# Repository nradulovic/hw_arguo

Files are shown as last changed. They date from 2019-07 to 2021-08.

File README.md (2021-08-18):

Compact amplifier
=================

This amplifier is intended to be used as a small desktop amplifier. It has no
fancy stuff. It does not even have a volume knob.

It has a short-circuit protection and all the necessary filtering on the inputs
and outputs.

The input is single-ended. 

It has two types of boards:
 - Amplifier board: Mono channel.
 - Power supply board with speaker protection & mute and LED indication.

The complete model of the amplifier case layout is based on Dayens Ampino power 
amplifier.

Amplifier board
===============

Description
-----------

The board contains one amplifier with short-circuit proction and input and
output filters.

Dimensions
----------

Max width: 200mm
Max height: 100mm

Connections
-----------

* Power supply connectors: Vcc, GND, Vee.
* Output connectors: Out, GND.
* Input connector: In, SGND.

Power supply board
==================

Description
-----------

Dimensions
----------

Max width: 140mm
Max height: 100mm

Connections
-----------

* AC Voltage input: Live, Neutral, Earth.
* Switch: CN1, CN2.
* Primary output: Live, Neutral, Earth.
* Secondary input: AC1, GND, AC2.
* DC output: Vcc, GND, Vee.
* Amplifier input: OutL, GND, OutR, GND
* Amplifier output: OutL, GND, OutR, GND
* LED indicator (POWER/FAILURE/OVERLOAD): Anode, Cathode.
* Mute key: K1, K2.

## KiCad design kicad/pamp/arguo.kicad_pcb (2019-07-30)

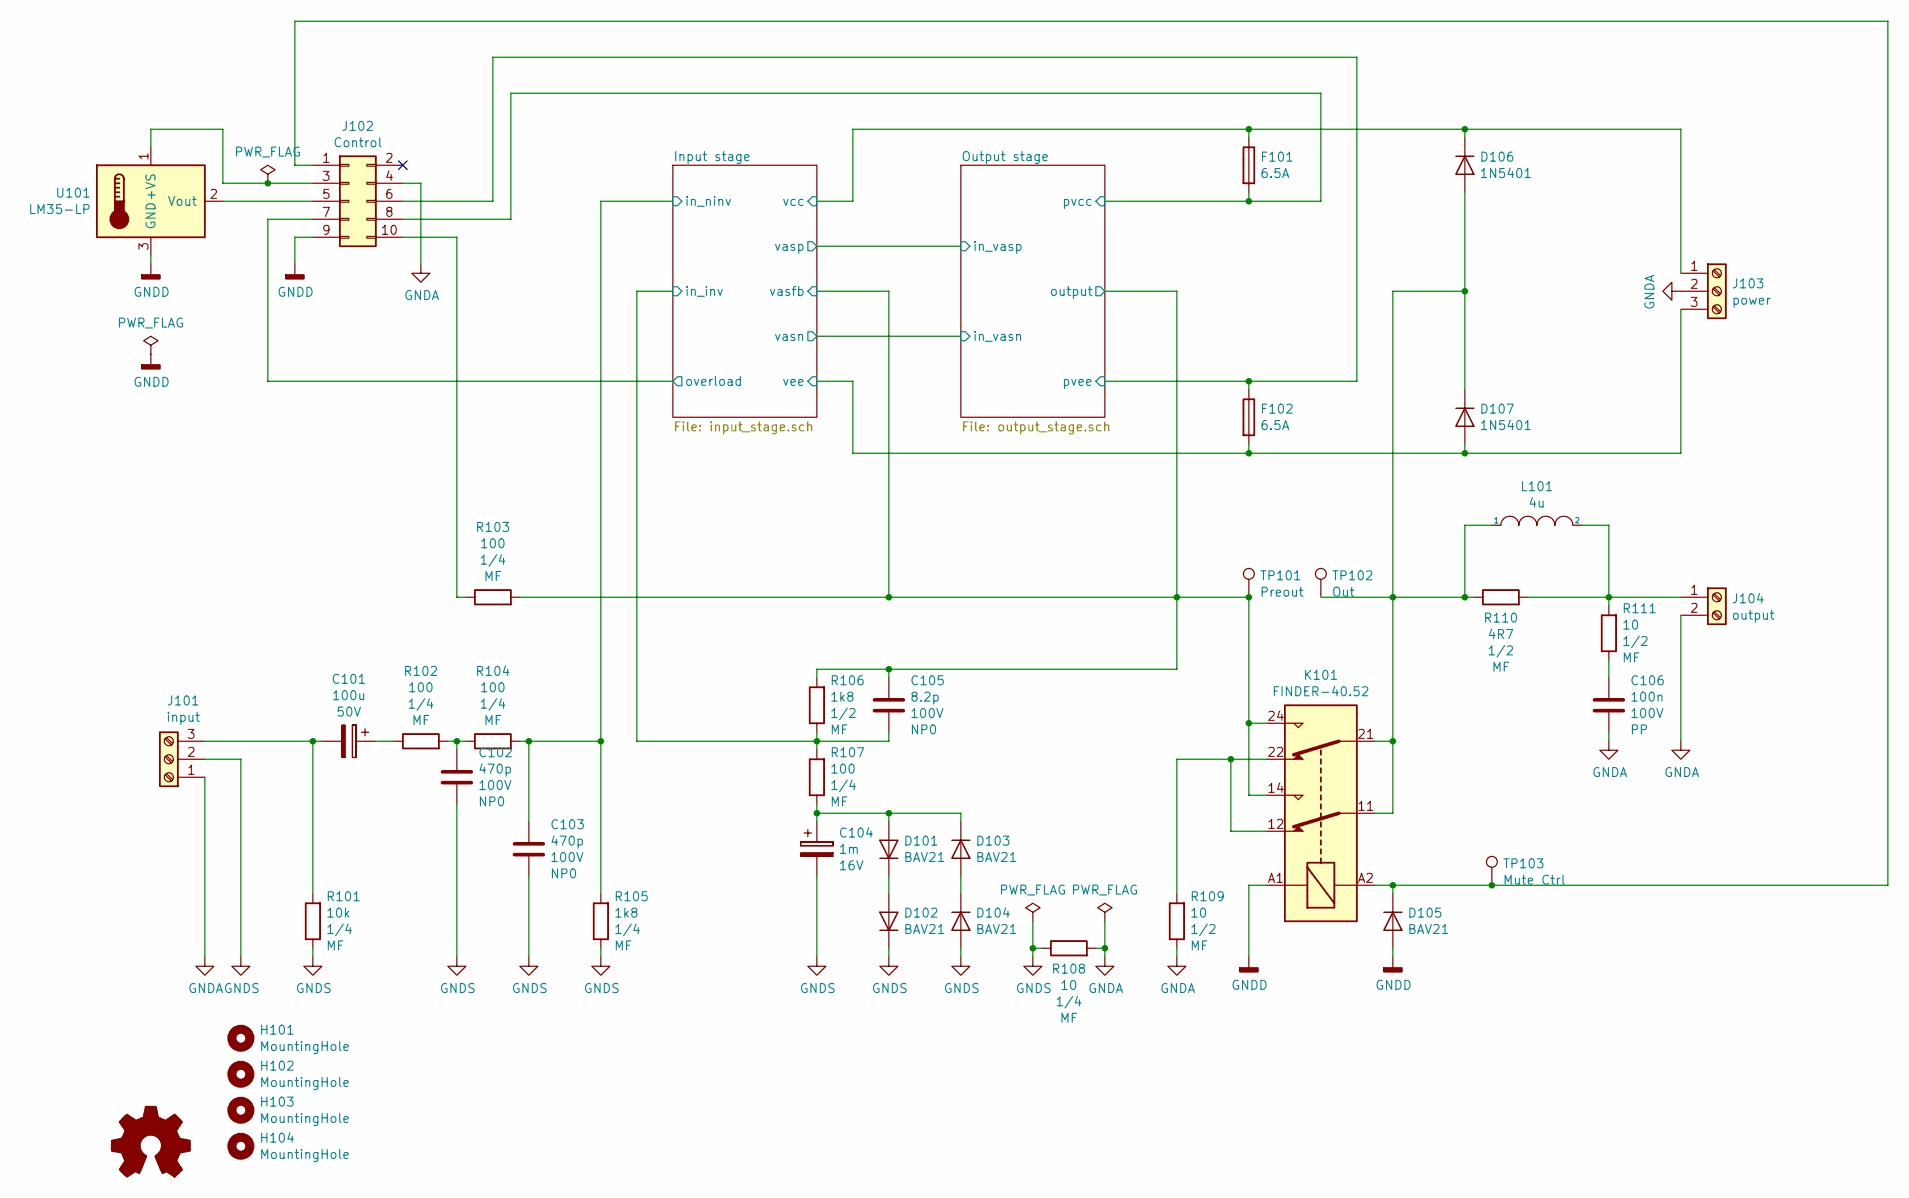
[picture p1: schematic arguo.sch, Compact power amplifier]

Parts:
C101: 100u; CP_Radial_D10.0mm_P3.50mm; Voltage 50V
C102, C103: 470p; C_Disc_D8.0mm_W2.5mm_P5.00mm; Voltage 100V
C104: 1m; CP_Radial_D10.0mm_P3.50mm; Voltage 16V
C105: 8.2p; C_Disc_D3.0mm_W2.0mm_P2.50mm; Voltage 100V
C106: 100n; C_Rect_L7.2mm_W5.5mm_P5.00mm_FKS2_FKP2_MKS2_MKP2; Voltage 100V
D101, D102, D103, D104, D105: BAV21; D_DO-41_SOD81_P7.62mm_Horizontal
D106, D107: 1N5401; D_DO-201AD_P15.24mm_Horizontal
F101, F102: 6.5A; Fuseholder_Cylinder-5x20mm_Schurter_0031_8201_Horizontal_Op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
H101, H102, H103, H104: MountingHole; MountingHole_3.2mm_M3_Pad
J101: input; TerminalBlock_Phoenix_PT-1,5-3-3.5-H_1x03_P3.50mm_Horizontal
J102: Control; IDC-Header_2x05_P2.54mm_Vertical
J103: power; PhoenixContact_MCV_1,5_3-G-3.81_1x03_P3.81mm_Vertical
J104: output; PhoenixContact_MCV_1,5_2-G-3.81_1x02_P3.81mm_Vertical
K101: FINDER-40.52; Relay_DPDT_Finder_40.52
L101: 4u; L_Axial_L29.9mm_D14.0mm_P7.62mm_Vertical_Vishay_IHA-105
R101: 10k; R_Axial_DIN0207_L6.3mm_D2.5mm_P10.16mm_Horizontal
R102, R103, R104, R107: 100; R_Axial_DIN0207_L6.3mm_D2.5mm_P10.16mm_Horizontal
R105: 1k8; R_Axial_DIN0207_L6.3mm_D2.5mm_P10.16mm_Horizontal
R106: 1k8; R_Axial_DIN0411_L9.9mm_D3.6mm_P12.70mm_Horizontal
R108: 10; R_Axial_DIN0207_L6.3mm_D2.5mm_P10.16mm_Horizontal
R109, R111: 10; R_Axial_DIN0411_L9.9mm_D3.6mm_P12.70mm_Horizontal
R110: 4R7; R_Axial_DIN0411_L9.9mm_D3.6mm_P12.70mm_Horizontal
TP101: Preout; TestPoint_Bridge_Pitch2.54mm_Drill0.7mm
TP102: Out; TestPoint_Bridge_Pitch2.54mm_Drill0.7mm
TP103: Mute Ctrl; TestPoint_Bridge_Pitch2.54mm_Drill0.7mm
U101: LM35-LP; TO-92L_Inline_Wide

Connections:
/Input stage/in_inv: C105.2, R106.1, R107.2; also elsewhere on the board
/Input stage/in_ninv: C103.2, R104.2, R105.2; also elsewhere on the board
/Input stage/overload: J102.7; also elsewhere on the board
/Input stage/vcc: D106.1 (K), F101.1, J103.1; also elsewhere on the board
/Input stage/vee: D107.2 (A), F102.2, J103.3; also elsewhere on the board
/Output stage/output: C105.1, K101.14, K101.24, R103.2, R106.2, TP101.1; also elsewhere on the board
/Output stage/pvcc: F101.2, J102.8; also elsewhere on the board
/Output stage/pvee: F102.1, J102.6; also elsewhere on the board
GNDA: C106.2, J101.1, J102.4, J103.2, J104.2, R108.2, R109.1; also elsewhere on the board
GNDD: D105.2 (A), J102.9, K101.A1, U101.3 (GND)
GNDS: C102.1, C103.1, C104.2, D102.1 (K), D104.2 (A), J101.2, R101.1, R105.1, R108.1
unnamed: C101.1, R102.1
unnamed: C101.2, J101.3, R101.2
unnamed: C102.2, R102.2, R104.1
unnamed: C104.1, D101.2 (A), D103.1 (K), R107.1
unnamed: C106.1, R111.1
unnamed: D101.1 (K), D102.2 (A)
unnamed: D103.2 (A), D104.1 (K)
unnamed: D105.1 (K), J102.1, K101.A2, TP103.1
unnamed: D106.2 (A), D107.1 (K), K101.11, K101.21, L101.1, R110.1, TP102.1
unnamed: J102.3, U101.1 (+VS)
unnamed: J102.5, U101.2 (Vout)
unnamed: J102.10, R103.1
unnamed: J104.1, L101.2, R110.2, R111.2
unnamed: K101.12, K101.22, R109.2

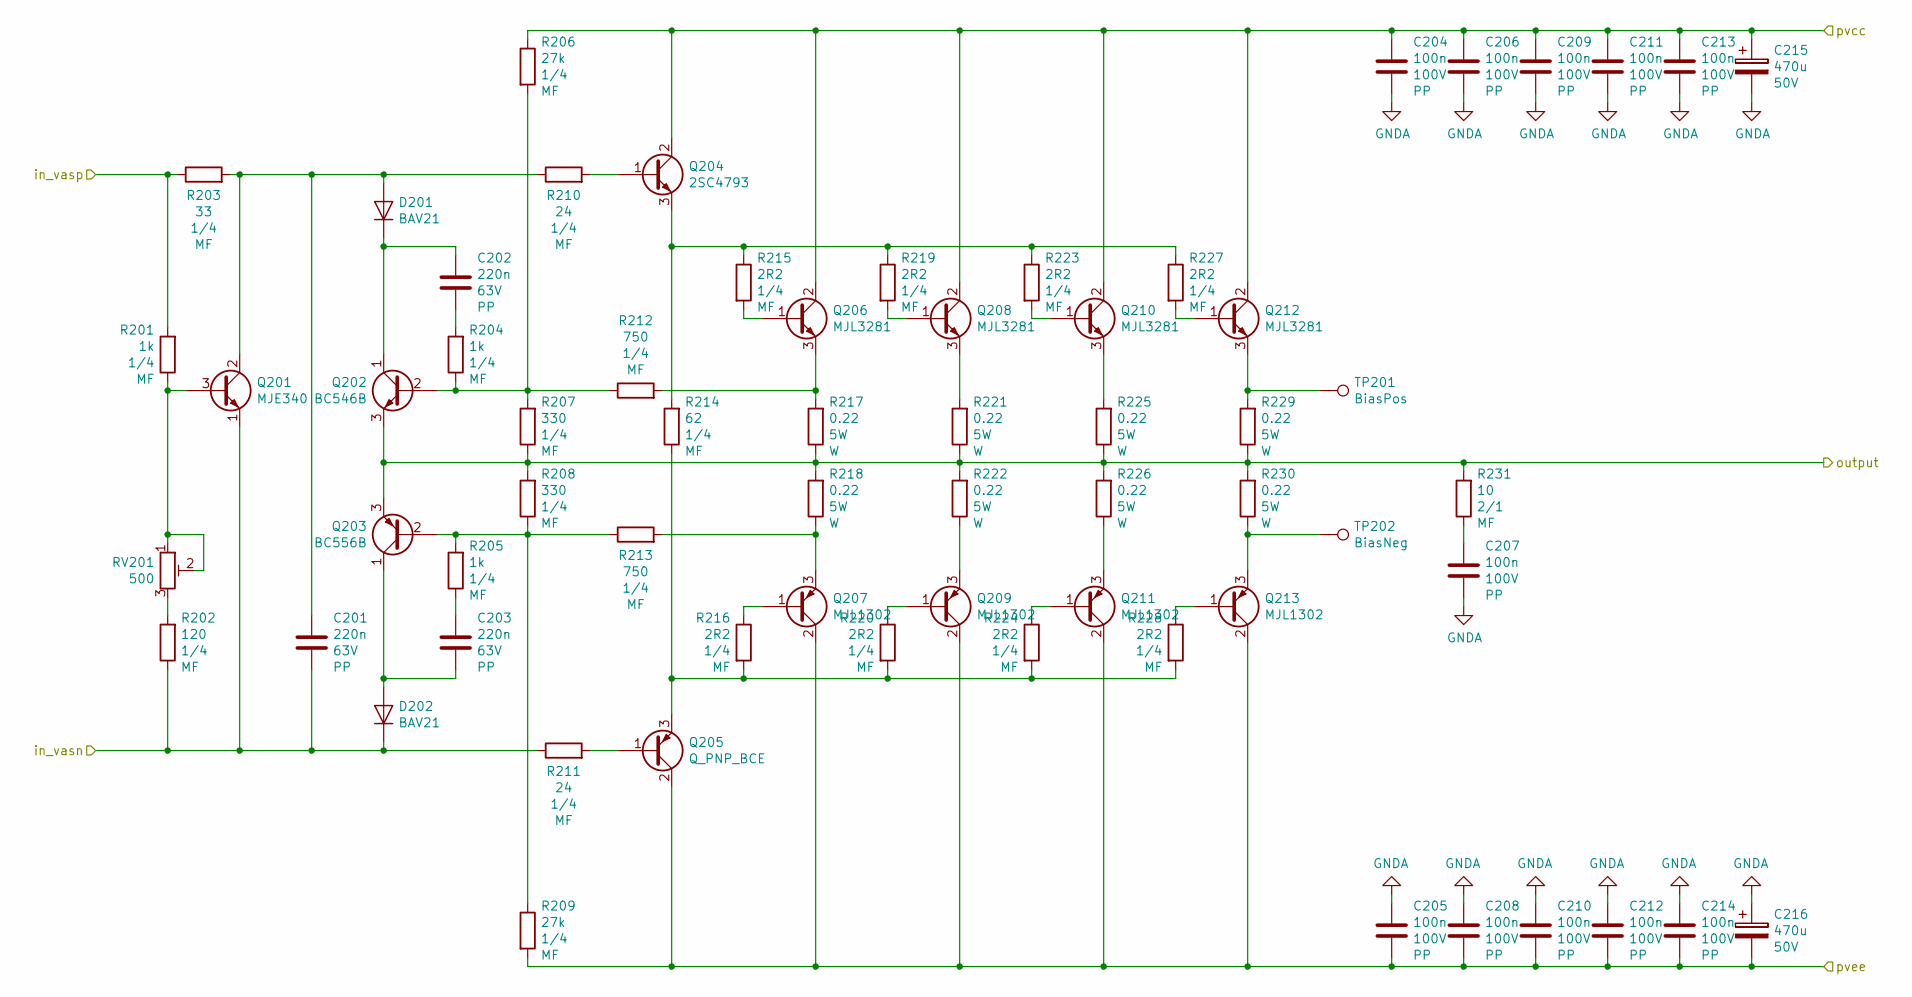
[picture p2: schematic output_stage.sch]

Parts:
C201, C202, C203: 220n; C_Rect_L7.2mm_W4.5mm_P5.00mm_FKS2_FKP2_MKS2_MKP2; Voltage 63V
C204, C205, C206, C207, C208, C209, C210, C211, C212, C213, C214: 100n; C_Rect_L7.2mm_W5.5mm_P5.00mm_FKS2_FKP2_MKS2_MKP2; Voltage 100V
C215, C216: 470u; CP_Radial_D17.0mm_P7.50mm; Voltage 50V
D201, D202: BAV21; D_DO-41_SOD81_P7.62mm_Horizontal
Q201: MJE340; TO-126-3_Vertical
Q202: BC546B; TO-92L_Inline_Wide
Q203: BC556B; TO-92L_Inline_Wide
Q204: 2SC4793; TO-220-3_Vertical
Q205: Q_PNP_BCE; TO-220-3_Vertical
Q206, Q208, Q210, Q212: MJL3281; TO-264-3_Vertical
Q207, Q209, Q211, Q213: MJL1302; TO-264-3_Vertical
R201, R204, R205: 1k; R_Axial_DIN0207_L6.3mm_D2.5mm_P10.16mm_Horizontal
R202: 120; R_Axial_DIN0207_L6.3mm_D2.5mm_P10.16mm_Horizontal
R203: 33; R_Axial_DIN0207_L6.3mm_D2.5mm_P10.16mm_Horizontal
R206, R209: 27k; R_Axial_DIN0207_L6.3mm_D2.5mm_P10.16mm_Horizontal
R207, R208: 330; R_Axial_DIN0207_L6.3mm_D2.5mm_P10.16mm_Horizontal
R210, R211: 24; R_Axial_DIN0207_L6.3mm_D2.5mm_P10.16mm_Horizontal
R212, R213: 750; R_Axial_DIN0207_L6.3mm_D2.5mm_P10.16mm_Horizontal
R214: 62; R_Axial_DIN0207_L6.3mm_D2.5mm_P10.16mm_Horizontal
R215, R216, R219, R220, R223, R224, R227, R228: 2R2; R_Axial_DIN0207_L6.3mm_D2.5mm_P10.16mm_Horizontal
R217, R218, R221, R222, R225, R226, R229, R230: 0.22; R_Axial_Power_L20.0mm_W6.4mm_P25.40mm
R231: 10; R_Axial_DIN0411_L9.9mm_D3.6mm_P12.70mm_Horizontal
RV201: 500; Potentiometer_ACP_CA9-V10_Vertical
TP201: BiasPos; TestPoint_Bridge_Pitch2.54mm_Drill0.7mm
TP202: BiasNeg; TestPoint_Bridge_Pitch2.54mm_Drill0.7mm

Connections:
/Output stage/in_vasn: C201.2, D202.1 (K), Q201.1 (E), R202.1, R211.1; also elsewhere on the board
/Output stage/in_vasp: R201.2, R203.1; also elsewhere on the board
/Output stage/output: Q202.3 (E), Q203.3 (E), R207.1, R208.2, R217.1, R218.2, R221.1, R222.2, R225.1, R226.2, R229.1, R230.2, R231.2; also elsewhere on the board
/Output stage/pvcc: C204.1, C206.1, C209.1, C211.1, C213.1, C215.1, Q204.2 (C), Q206.2 (C), Q208.2 (C), Q210.2 (C), Q212.2 (C), R206.1; also elsewhere on the board
/Output stage/pvee: C205.2, C208.2, C210.2, C212.2, C214.2, C216.2, Q205.2 (C), Q207.2 (C), Q209.2 (C), Q211.2 (C), Q213.2 (C), R209.2; also elsewhere on the board
GNDA: C204.2, C205.1, C206.2, C207.2, C208.1, C209.2, C210.1, C211.2, C212.1, C213.2, C214.1, C215.2, C216.1; also elsewhere on the board
unnamed: C201.1, D201.2 (A), Q201.2 (C), R203.2, R210.1
unnamed: C202.1, D201.1 (K), Q202.1 (C)
unnamed: C202.2, R204.2
unnamed: C203.1, R205.1
unnamed: C203.2, D202.2 (A), Q203.1 (C)
unnamed: C207.1, R231.1
unnamed: Q201.3 (B), R201.1, RV201.1, RV201.2
unnamed: Q202.2 (B), R204.1, R206.2, R207.2, R212.1
unnamed: Q203.2 (B), R205.2, R208.1, R209.1, R213.1
unnamed: Q204.1 (B), R210.2
unnamed: Q204.3 (E), R214.2, R215.1, R219.1, R223.1, R227.1
unnamed: Q205.1 (B), R211.2
unnamed: Q205.3 (E), R214.1, R216.2, R220.2, R224.2, R228.2
unnamed: Q206.1 (B), R215.2
unnamed: Q206.3 (E), R212.2, R217.2
unnamed: Q207.1 (B), R216.1
unnamed: Q207.3 (E), R213.2, R218.1
unnamed: Q208.1 (B), R219.2
unnamed: Q208.3 (E), R221.2
unnamed: Q209.1 (B), R220.1
unnamed: Q209.3 (E), R222.1
unnamed: Q210.1 (B), R223.2
unnamed: Q210.3 (E), R225.2
unnamed: Q211.1 (B), R224.1
unnamed: Q211.3 (E), R226.1
unnamed: Q212.1 (B), R227.2
unnamed: Q212.3 (E), R229.2, TP201.1
unnamed: Q213.1 (B), R228.1
unnamed: Q213.3 (E), R230.1, TP202.1
unnamed: R202.2, RV201.3

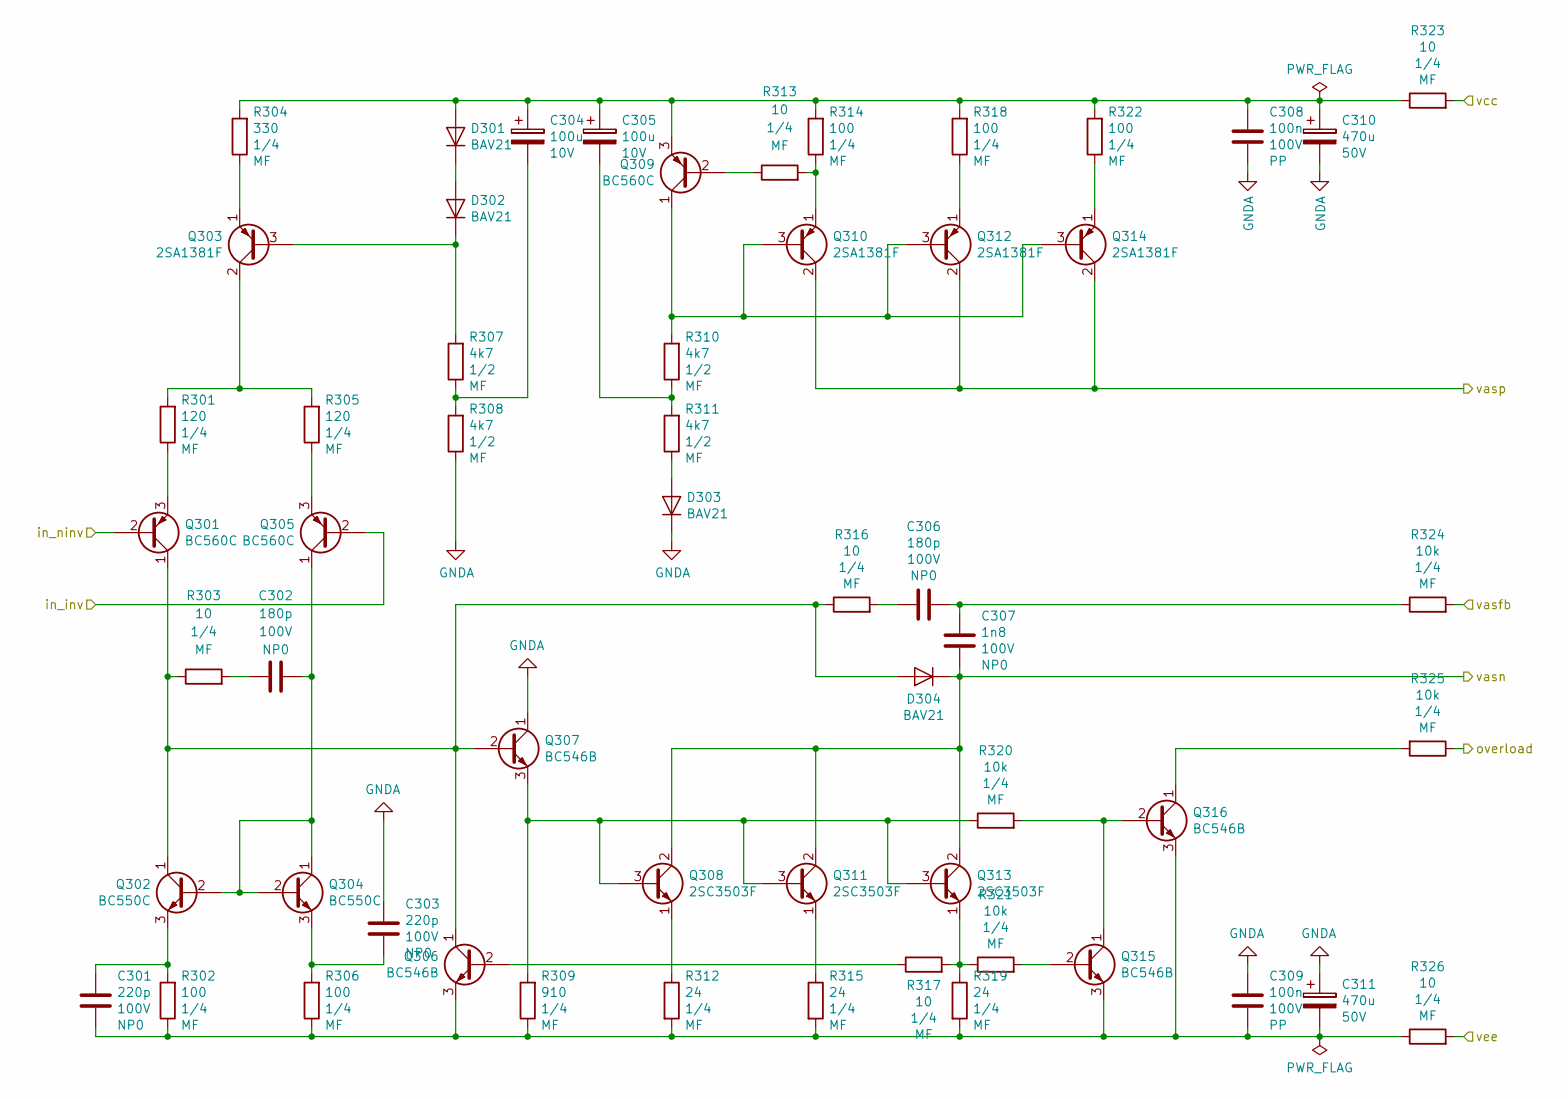
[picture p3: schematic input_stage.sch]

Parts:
C301, C303: 220p; C_Disc_D8.0mm_W2.5mm_P5.00mm; Voltage 100V
C302, C306: 180p; C_Disc_D8.0mm_W2.5mm_P5.00mm; Voltage 100V
C304, C305: 100u; CP_Radial_D8.0mm_P2.50mm; Voltage 10V
C307: 1n8; C_Disc_D8.0mm_W2.5mm_P5.00mm; Voltage 100V
C308, C309: 100n; C_Rect_L7.2mm_W5.5mm_P5.00mm_FKS2_FKP2_MKS2_MKP2; Voltage 100V
C310, C311: 470u; CP_Radial_D10.0mm_P3.50mm; Voltage 50V
D301, D302, D303, D304: BAV21; D_DO-41_SOD81_P7.62mm_Horizontal
Q301, Q305, Q309: BC560C; TO-92L_Inline_Wide
Q302, Q304: BC550C; TO-92L_Inline_Wide
Q303: 2SA1381F; TO-126-3_Vertical
Q306, Q307, Q315, Q316: BC546B; TO-92L_Inline_Wide
Q308, Q311, Q313: 2SC3503F; TO-126-3_Horizontal_TabDown
Q310, Q312, Q314: 2SA1381F; TO-126-3_Horizontal_TabDown
R301, R305: 120; R_Axial_DIN0207_L6.3mm_D2.5mm_P10.16mm_Horizontal
R302, R306, R314, R318, R322: 100; R_Axial_DIN0207_L6.3mm_D2.5mm_P10.16mm_Horizontal
R303, R313, R316, R317, R323, R326: 10; R_Axial_DIN0207_L6.3mm_D2.5mm_P10.16mm_Horizontal
R304: 330; R_Axial_DIN0207_L6.3mm_D2.5mm_P10.16mm_Horizontal
R307, R308, R310, R311: 4k7; R_Axial_DIN0411_L9.9mm_D3.6mm_P12.70mm_Horizontal
R309: 910; R_Axial_DIN0207_L6.3mm_D2.5mm_P10.16mm_Horizontal
R312, R315, R319: 24; R_Axial_DIN0207_L6.3mm_D2.5mm_P10.16mm_Horizontal
R320, R321, R324, R325: 10k; R_Axial_DIN0207_L6.3mm_D2.5mm_P10.16mm_Horizontal

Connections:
/Input stage/in_inv: Q305.2 (B); also elsewhere on the board
/Input stage/in_ninv: Q301.2 (B); also elsewhere on the board
/Input stage/overload: R325.1; also elsewhere on the board
/Input stage/vcc: R323.2; also elsewhere on the board
/Input stage/vee: R326.2; also elsewhere on the board
/Output stage/in_vasn: C307.1, D304.1 (K), Q308.2 (C), Q311.2 (C), Q313.2 (C); also elsewhere on the board
/Output stage/in_vasp: Q310.2 (C), Q312.2 (C), Q314.2 (C); also elsewhere on the board
/Output stage/output: R324.2; also elsewhere on the board
GNDA: C303.2, C308.2, C309.1, C310.2, C311.1, D303.1 (K), Q307.1 (C), R308.1; also elsewhere on the board
unnamed: C301.1, C309.2, C311.2, Q306.3 (E), Q315.3 (E), Q316.3 (E), R302.1, R306.1, R309.1, R312.2, R315.2, R319.2, R326.1
unnamed: C301.2, Q302.3 (E), R302.2
unnamed: C302.1, Q302.2 (B), Q304.1 (C), Q304.2 (B), Q305.1 (C)
unnamed: C302.2, R303.2
unnamed: C303.1, Q304.3 (E), R306.2
unnamed: C304.1, C305.1, C308.1, C310.1, D301.2 (A), Q309.3 (E), R304.2, R314.2, R318.2, R322.2, R323.1
unnamed: C304.2, R307.1, R308.2
unnamed: C305.2, R310.1, R311.2
unnamed: C306.1, C307.2, R324.1
unnamed: C306.2, R316.2
unnamed: D301.1 (K), D302.2 (A)
unnamed: D302.1 (K), Q303.3 (B), R307.2
unnamed: D303.2 (A), R311.1
unnamed: D304.2 (A), Q301.1 (C), Q302.1 (C), Q306.1 (C), Q307.2 (B), R303.1, R316.1
unnamed: Q301.3 (E), R301.1
unnamed: Q303.1 (E), R304.1
unnamed: Q303.2 (C), R301.2, R305.2
unnamed: Q305.3 (E), R305.1
unnamed: Q306.2 (B), R317.1
unnamed: Q307.3 (E), Q308.3 (B), Q311.3 (B), Q313.3 (B), R309.2, R320.1
unnamed: Q308.1 (E), R312.1
unnamed: Q309.1 (C), Q310.3 (B), Q312.3 (B), Q314.3 (B), R310.2
unnamed: Q309.2 (B), R313.1
unnamed: Q310.1 (E), R313.2, R314.1
unnamed: Q311.1 (E), R315.1
unnamed: Q312.1 (E), R318.1
unnamed: Q313.1 (E), R317.2, R319.1, R321.1
unnamed: Q314.1 (E), R322.1
unnamed: Q315.1 (C), Q316.2 (B), R320.2
unnamed: Q315.2 (B), R321.2
unnamed: Q316.1 (C), R325.2

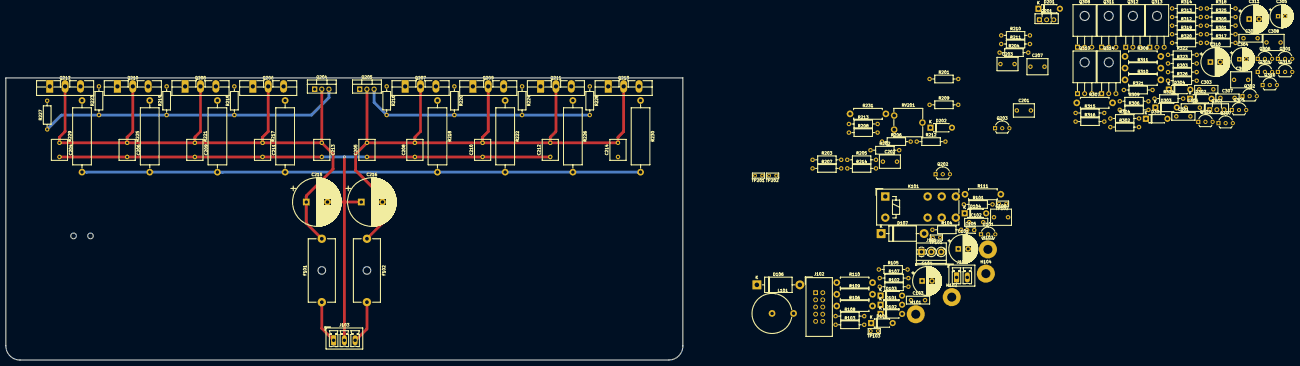
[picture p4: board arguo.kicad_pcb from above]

Board: 2 copper layers, 240.0 x 100.0 mm, 162 parts (0 on the bottom side), 88 nets.

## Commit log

2019-07-30 Solution 1. for high current routing.
    [arguo.kicad_pcb, arguo.sch, input_stage.sch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]
2020-04-22 Added protection calculation excel sheet.
    [paX_prot_calc_master_reworked.xls]
